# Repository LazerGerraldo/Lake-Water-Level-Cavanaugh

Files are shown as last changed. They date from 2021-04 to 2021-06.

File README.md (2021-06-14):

# Lake-Water-Level-Cavanaugh

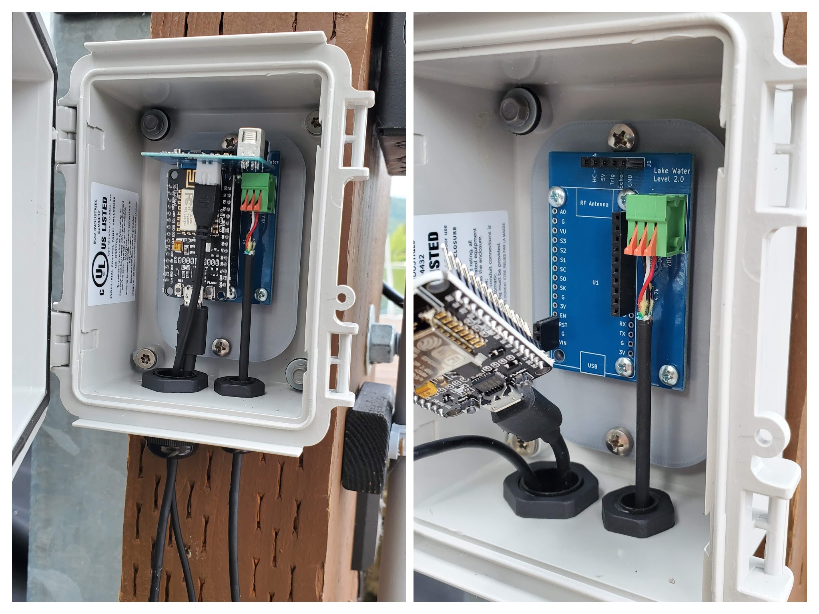
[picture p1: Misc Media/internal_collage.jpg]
electronic devices mounted to small box on wall


I began by seting up the DS18B20 temperature sensor with the ESP8266 shown in the TempSensor8266.ino file. 
After gaining comfort with the ESP8266 and how it differs from an Arduino Nano or Arduino Uno I then followed [the tutorial by Random Nerd Tutorials](https://randomnerdtutorials.com/esp32-esp8266-publish-sensor-readings-to-google-sheets/)  to setup measurement recordings using Google Sheets.

Along the way I was able to combine what I knew about the temperature sensor and the above Google Sheets example and recorded temperatures. That quickly became another project for my aquarium in monitoring the temperature throughout the day. Back to the lake level project. One important thing to note was the need to connect the RST pin to GPIO 16 on the ESP8266 after programming to enable the `
ESP.deepSleep()` cycle. This was a new thing for me and the [article here](https://randomnerdtutorials.com/esp8266-deep-sleep-with-arduino-ide/) goes into more depth.

I received the HC-SR04 Ultrasonic Distance sensor and took a step back. I have found that its important to not pile too much into a project at one time without any opportunity for debugging and solving unexpected problems. With that I moved back to the TempSensor8266.ino file and copied that over to a new project SonarTemp8266.ino, and made sure the sensor interface with the ESP8266 works. I followed the [guide by Makerguides.com here](https://www.makerguides.com/jsn-sr04t-arduino-tutorial/)

Learned that D2 pin does not mean pin 2, in fact it correlates to 4 in the Arduino IDE. I followed the [image here](https://www.electronicwings.com/nodemcu/nodemcu-gpio-with-arduino-ide). The GPIO pin number matters over the digital pin number. 

Here is the datasheet for the [HC-SR04 Ultrasonic Distance sensor](https://www.makerguides.com/wp-content/uploads/2019/02/HCSR04-Datasheet.pdf)

I encountered a problem with the baud rate or symbol rate that the ESP8266 uses for the temperature sensor is different than that of the sonar sensor. The sonar sensor operates at 9600 baud while the temperature sensor examples that I was working off of used 115200. This became quite an obstacle for me as using two separate baud rates on a single device depends on the hardware available. My solution was picking the more standard baud of 9600 as I learned the temperature sensor actually works at both rates. This solution is shown in the SonarTemp.ino.

I got the two sensors working and sending outputs that looked like this 
```` 
22.13ºC
71.82ºF
Distance = 28.34 in
```` 
So awesome! 

Using a tape measure and a cardboard box, I placed the box at the end of the tape measure and moved the sonar sensor along the tape measure taking note of the difference in length in the measured distance and the actual length. An adjustment of 1.17 in was added to the output distance value. 

The sonar sensor had a bit of an angle to the  direction of propagation. As a verification of distance measurements and their accuracy, I measured the distance from the hardwood floor, to the bottom edge of the table top, where the sensor would rest at 28.4 in. The measured distance from sensor to floor came in at 28.34 in, a 0.06 in difference I can live with.

With both major sensing components working synchronously, I moved on to outputting measurements to the Google Sheets document. 

Moved Echo pin on the HC-SR04 from GPPIO pin 0 to 10, as pin 0 has to do with the FLASH function of the ESP8266 and that interfered with the uploading and flashing of new code. 

To get the resource variable from [Webhooks](https://ifttt.com/maker_webhooks) and place the resource variable in my code. Mine was something like `"/trigger/lake_water_level/with/key/nAZjOphL3d-1A7gTlNSrxMJdmqy3"`

Field testing was a success, the Wi-Fi range of ~75ft worked. Had a hard time after the initial testing phase in the field with the program rebooting after power loss. I followed the [ESP8266 Pinout Reference](https://randomnerdtutorials.com/esp8266-pinout-reference-gpios/) guide here and determined the pins I had connected sensors to were causing a fail in reboot. I was using GPIO0 and GPIO2 both of which cause boot to fail when pulled low due to their connection to the HC-SR04. To solve the booting issue, the Echo pin moved to GPIO12 and the Trig pin to GPIO14 as both of those GPIO ports were recommended by the ESP8266 Pinout Reference webpage. That solved the problem for me. 

The example code that I was working with clocked out after five failed WiFi connection attempts. Since this project does not take into consideration the amount of power used, nor any signal interference that may be created, an infinite loop of connection to WiFi was needed. 

<details>
  <summary>WiFi Connection Loop Code Change</summary>

    ````
    while(!!!client.connect(server, 80)) { // keep trying to connect to WiFi until connection is made
        Serial.print(".");
    }
    ````
    
</details>

The final schematic of the data logger device. 
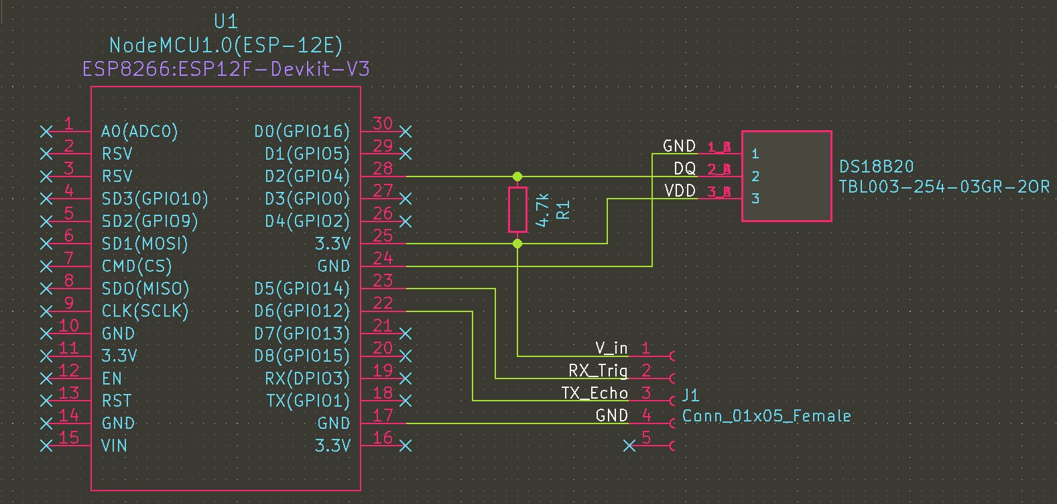
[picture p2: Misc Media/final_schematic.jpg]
electronic schematic layout


It actually took me two attempts at making a PCB, this was my first time and I did expect something like this to happen. 
I used the given KiCad footprints and did not discover until I was wiring up that I had picked the incorrect footprint for the female pin headers. I had 2.54mm female pin headers on hand, and the PCB holes were much smaller. Not a problem, there were a few other design changes that I wished to make and it all worked out for the best. You can see in the picture below some of the changes I made to the PCB, the smaller board was the first PCB.

<details>
  <summary>PCB Comparison</summary>
    
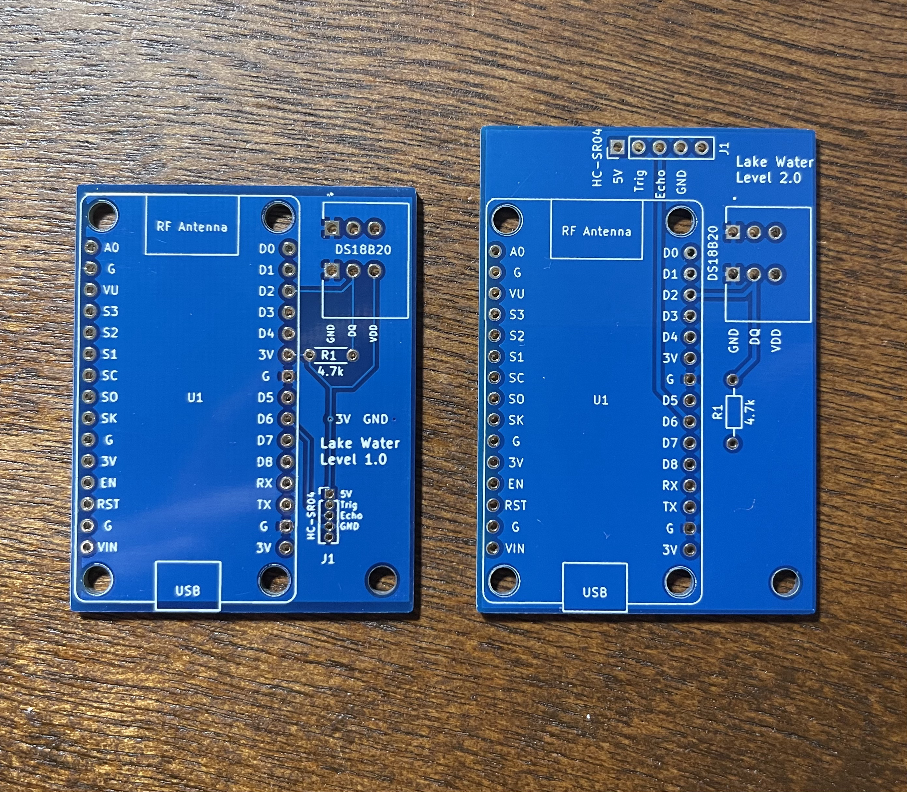
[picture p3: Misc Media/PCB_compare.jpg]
blue printed circuit boards on a table


</details>

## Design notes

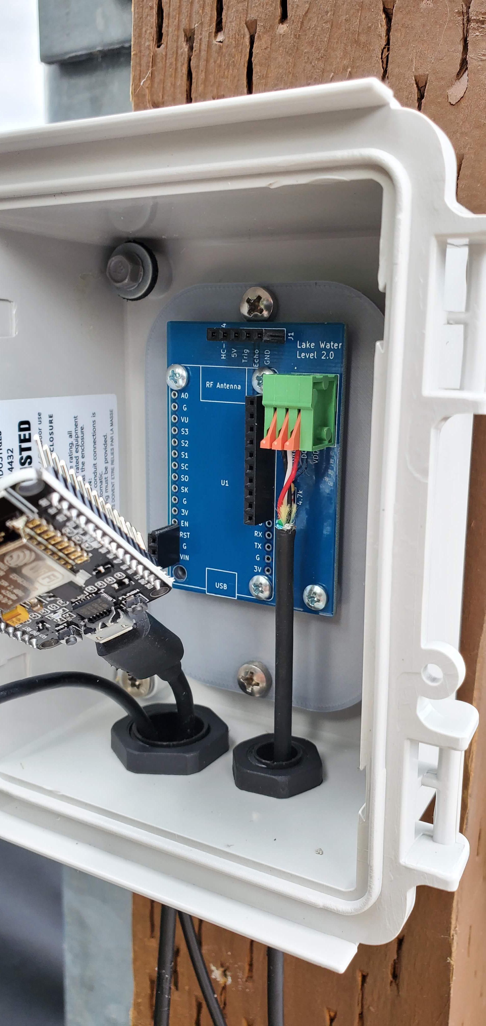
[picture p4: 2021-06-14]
Misc Media/mounting_image.jpg

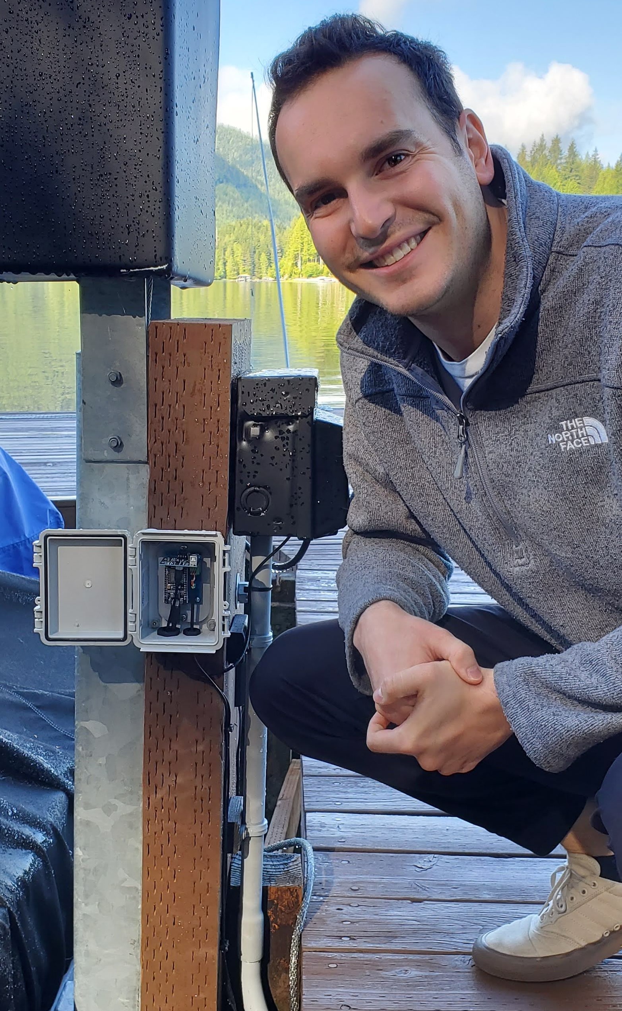
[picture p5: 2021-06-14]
Misc Media/group_photo.jpg

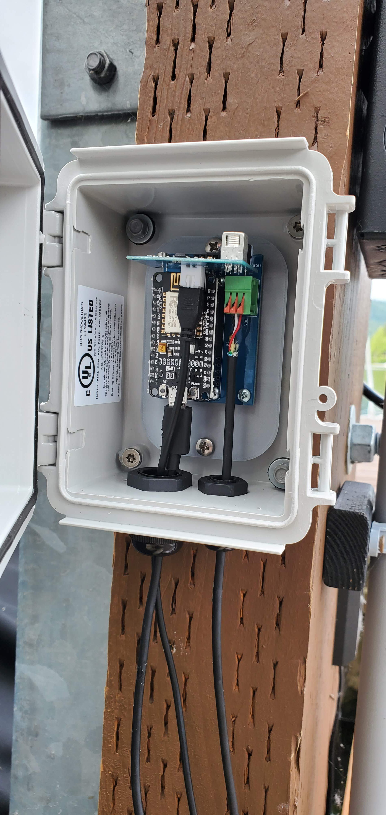
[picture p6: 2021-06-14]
Misc Media/internal.jpg

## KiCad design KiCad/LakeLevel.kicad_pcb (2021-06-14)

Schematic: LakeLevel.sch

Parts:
DS18B20: TBL003-254-03GR-2OR; CUI_TBL003-254-03GR-2OR
J1: Conn_01x05_Female; PinHeader_1x05_P2.54mm_Vertical
R1: 4.7k; R_Axial_DIN0204_L3.6mm_D1.6mm_P7.62mm_Horizontal
U1: NodeMCU1.0(ESP-12E); ESP12F-Devkit-V3

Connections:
/DQ: DS18B20.2_A (2), DS18B20.2_B (2), R1.2, U1.28
/GND: DS18B20.1_A (1), DS18B20.1_B (1), J1.4, U1.17, U1.24
/RX_Trig: J1.2, U1.23
/TX_Echo: J1.3, U1.22
/VDD: DS18B20.3_A (3), DS18B20.3_B (3), J1.1, R1.1, U1.25

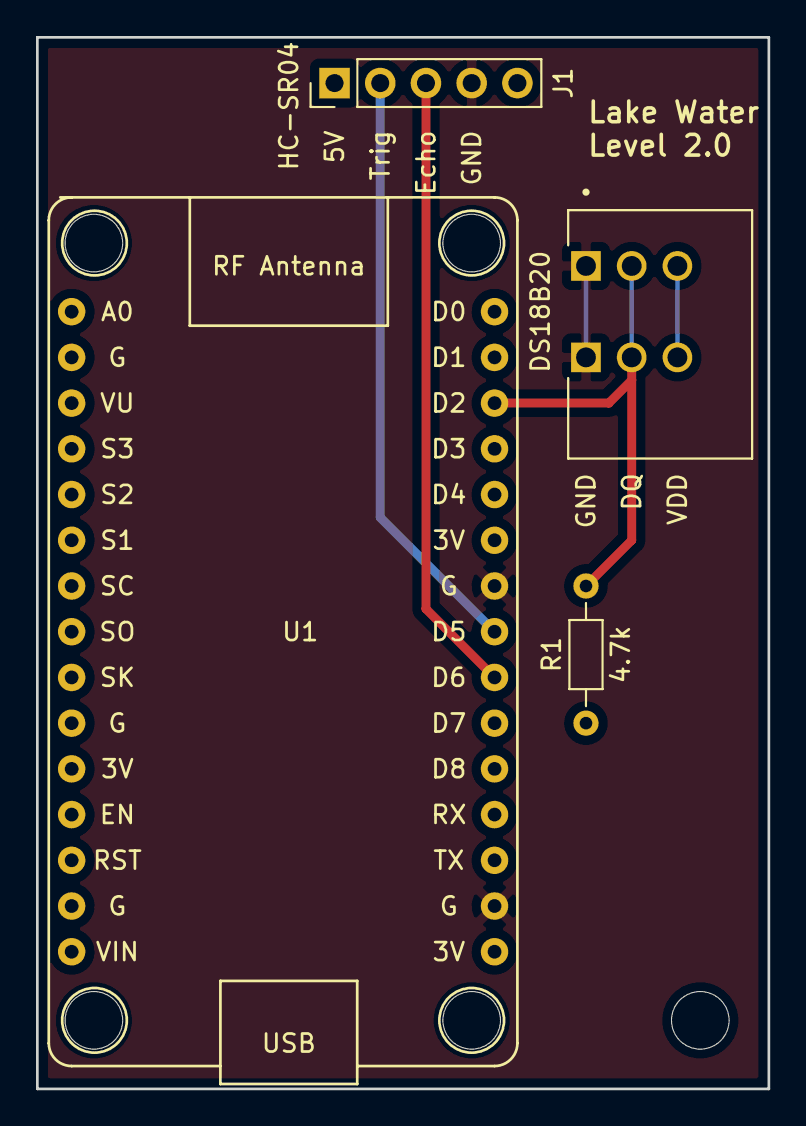
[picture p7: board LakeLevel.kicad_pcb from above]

Board: 2 copper layers, 40.6 x 58.4 mm, 4 parts (0 on the bottom side), 5 nets.

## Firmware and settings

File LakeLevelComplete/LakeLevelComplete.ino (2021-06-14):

/*
 * Jamie Bernard
 * 4/7/2021 
 *  Sonar sensor and temperature sensors hooked up to ESP8266 to measure and record 
 *  temperature of body of water, and distance of 
 */
 
#ifdef ESP32
  #include <WiFi.h>
#else
  #include <ESP8266WiFi.h>
#endif

// Define Trig and Echo pin for JSN-SR04T
#define trigPin 14
#define echoPin 12

// DS18B20 connections
#include <OneWire.h>            // include temp sensor
#include <DallasTemperature.h>  // include temp sensor
#include <Wire.h>

// Replace with your SSID and Password
const char* ssid     = "SSID";
const char* password = "Password";

// GPIO where the DS18B20 is connected to
const int oneWireBus = 4;
// Setup a oneWire instance to communicate with DS18B20
OneWire oneWire(oneWireBus);
// Pass our oneWire reference to Dallas Temperature sensor 
DallasTemperature sensors(&oneWire);

// Define variables:
float distInch;  // distance measured in in
int sensorHeight = 1013; // altitude adjustment of lake level
// Time to sleep
uint64_t TIME_TO_SLEEP = 1800000; // in milliseconds 12 hours 43200000 milliseconds, 60000 milliseconds in one minute for testing

// Replace with your unique IFTTT URL resource
const char* resource = "See Example resource variable below, should be your own api key";
// How your resource variable should look like, but with your own API KEY (that API KEY below is just an example):
//const char* resource = "/trigger/bme280_readings/with/key/nAZjOphL3d-ZO4N3k64-1A7gTlNSrxMJdmqy3";

// Maker Webhooks IFTTT
const char* server = "maker.ifttt.com";
#define SEALEVELPRESSURE_HPA (1013.25)

void setup() {
  delay(2000);
  
  // Define inputs and outputs of JSN-SR04T
  pinMode(trigPin, OUTPUT);
  pinMode(echoPin, INPUT);
  
  // Begin Serial communication at a baudrate of 9600:
  Serial.begin(9600);
  // Start the DS18B20 sensor
  sensors.begin();
  Serial.println("********runing setup********");
}

void loop() {
//  setup();
  initWifi();
  makeIFTTTRequest();

  Serial.println("********Sleeping********");
  delay(TIME_TO_SLEEP);
  Serial.println("********AWAKE********");
  Serial.println("........starting loop again");
}

// Establish a Wi-Fi connection with your router
void initWifi() {
  Serial.print("Connecting to: "); 
  Serial.print(ssid);
  WiFi.begin(ssid, password);  

  int timeout = 10 * 4; // 10 seconds
  while(WiFi.status() != WL_CONNECTED  && (timeout-- > 0)) {
    delay(250);
    Serial.print(".");
  }
  Serial.println("");

  if(WiFi.status() != WL_CONNECTED) {
     Serial.println("Failed to connect, going back to sleep");
  }

  Serial.print("WiFi connected in: "); 
  Serial.print(millis());
  Serial.print(", IP address: "); 
  Serial.println(WiFi.localIP());
}

// Make an HTTP request to the IFTTT web service
void makeIFTTTRequest() {
  Serial.print("Connecting to "); 
  Serial.print(server);
  
  WiFiClient client;
//  int retries = 5;
//  while(!!!client.connect(server, 80) && (retries-- > 0)) {
//    Serial.print(".");
//  }
  while(!!!client.connect(server, 80)) { // keep trying to connect to wifi until connection is made
    Serial.print(".");
  }
  Serial.println();
  if(!!!client.connected()) {
    Serial.println("Failed to connect...");
  }
  
  Serial.print("Request resource: "); 
  Serial.println(resource);

  //  run sonar sensor
  distInch = Sonar();
  
  sensors.requestTemperatures(); 
  float temperatureC = sensors.getTempCByIndex(0);
  float temperatureF = sensors.getTempFByIndex(0);

  // output object to 
  String jsonObject = String("{\"value1\":\"") + sensors.getTempFByIndex(0) + "\",\"value2\":\"" + sensors.getTempCByIndex(0) + "\",\"value3\":\"" + distInch + "\"}";
                      
  // Comment the previous line and uncomment the next line to publish temperature readings in Fahrenheit                    
  /*String jsonObject = String("{\"value1\":\"") + (1.8 * bme.readTemperature() + 32) + "\",\"value2\":\"" 
                      + (bme.readPressure()/100.0F) + "\",\"value3\":\"" + bme.readHumidity() + "\"}";*/
                      
  client.println(String("POST ") + resource + " HTTP/1.1");
  client.println(String("Host: ") + server); 
  client.println("Connection: close\r\nContent-Type: application/json");
  client.print("Content-Length: ");
  client.println(jsonObject.length());
  client.println();
  client.println(jsonObject);
        
  int timeout = 5 * 10; // 5 seconds             
  while(!!!client.available() && (timeout-- > 0)){
    delay(100);
  }
  if(!!!client.available()) {
    Serial.println("No response...");
  }
  while(client.available()){
    Serial.write(client.read());
  }
  
  Serial.println("\nclosing connection");
  client.stop(); 
}

// funciton to read and average sonar values over a set time period, returns the difference between the height 
//calibration (how high the sensor is above sea level) and the measured sonar distance
float Sonar(){
  long duration; // duration (length of JSN-SR04T sonar pulse) in microseconds
  float distance;  // distance measured by JSN-SR04T in cm
  float sumS = 0;   // sum of  given measurements
  int counts = 0; // number of measurements taken
  float level = 0;  // overall lake level

  // takes 50 measurments over the span of 
  while (counts <= 50){
    // Clear the trigPin by setting it LOW:
    digitalWrite(trigPin, LOW);   
    delayMicroseconds(5);
  
    // Trigger the sensor by setting the trigPin high for 10 microseconds:
    digitalWrite(trigPin, HIGH);
    delayMicroseconds(10);
    digitalWrite(trigPin, LOW);
    
    // Read the echoPin. pulseIn() returns the duration (length of the pulse) in microseconds:
    duration = pulseIn(echoPin, HIGH);
    distance = (duration*0.034/2.0) / 2.54 + 1.17; // divide by 2.54 for cm to inches add 1.17 inch calibration offset value
    distance = distance / 12.0; // convert from inches to feet
    
    if (distance <= 6){
      //debugging printing for absolute distance measurment in feet
//      Serial.print("Distance ");
//      Serial.println(distance);

      sumS = sumS + distance; // add current reading to sum of readings
      counts++;               // increment count
      level = sumS / counts;  // average total sum of measurements by number of measurements
    }
    delay(100);
  }
  Serial.println(level);
//  return level + sensorHeight;  // add sensorHeight offset value to final measured value
  return sensorHeight - level;    // subtract reading from sensor level
}

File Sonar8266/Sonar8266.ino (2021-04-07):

/* Arduino example sketch to control a JSN-SR04T ultrasonic distance sensor with Arduino. No library needed. More info: https://www.makerguides.com */

// Define Trig and Echo pin:
#define trigPin 2
#define echoPin 0

// Define variables:
long duration;
int distance;
int distInch;

void setup() {
  // Define inputs and outputs
  pinMode(trigPin, OUTPUT);
  pinMode(echoPin, INPUT);
  
  // Begin Serial communication at a baudrate of 9600:
  Serial.begin(9600);
}

void loop() {
  // Clear the trigPin by setting it LOW:
  digitalWrite(trigPin, LOW);
  
  delayMicroseconds(5);

 // Trigger the sensor by setting the trigPin high for 10 microseconds:
  digitalWrite(trigPin, HIGH);
  delayMicroseconds(10);
  digitalWrite(trigPin, LOW);
  
  // Read the echoPin. pulseIn() returns the duration (length of the pulse) in microseconds:
  duration = pulseIn(echoPin, HIGH);
  
  // Calculate the distance:
  distance = duration*0.034/2;
  
  // Print the distance on the Serial Monitor (Ctrl+Shift+M):
  Serial.print("Distance = ");
//  Serial.print(distance);
//  Serial.println(" cm");
  Serial.print(distance / 2.54 + 1.17); // convert to inches and add the calibration value
  Serial.println(" in");
  delay(100);
}
